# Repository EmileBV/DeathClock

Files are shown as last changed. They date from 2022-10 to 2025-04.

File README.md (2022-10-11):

# DeathClock
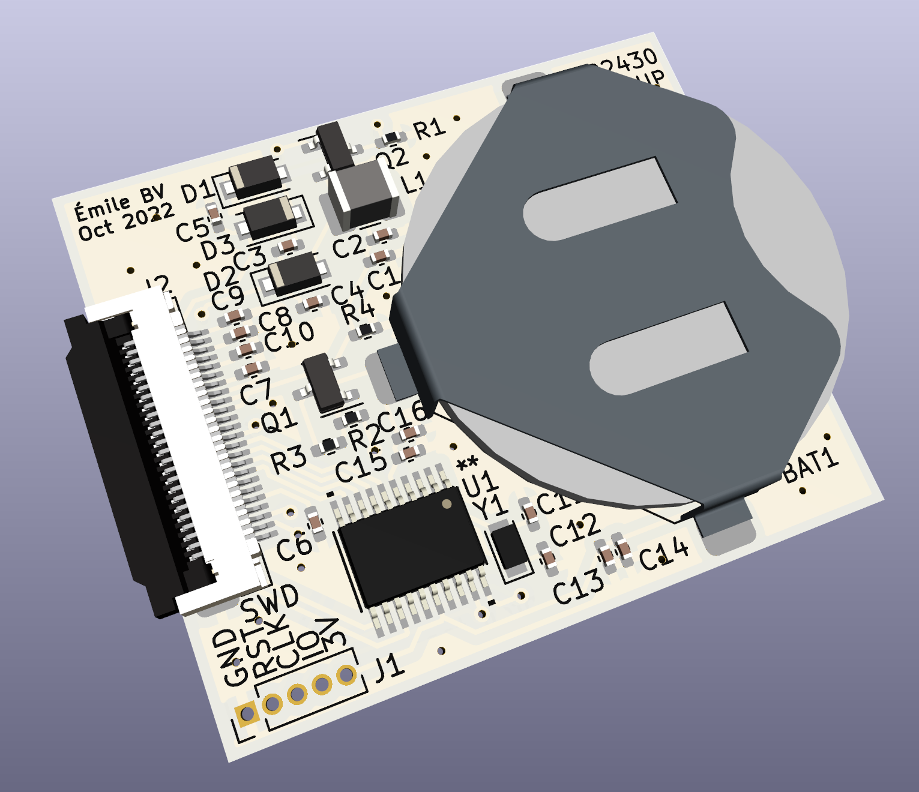
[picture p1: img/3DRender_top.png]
PCB 3D render


This project's goal to make a pocket "watch" that will last and run as long as possible and count down to a set date/time. Using an E-Paper display that will be updated maybe twice per day and a STM32L010xx MCU running on its internal low power clock to achieve very long runtime on a CR2430 coin cell.

This project is still in its very early stages right now, don't expect too much.

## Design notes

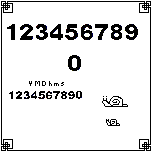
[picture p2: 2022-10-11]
img/border-1.png

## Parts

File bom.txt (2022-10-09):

screen
	https://www.mouser.ca/ProductDetail/Pervasive-Displays/E2154CS0C1?qs=81r%252BiQLm7BRJs1q0y8kw4A%3D%3D
	https://www.digikey.ca/short/02f04dr4
	E2154CS0C1 
	
mcu
	https://www.digikey.ca/short/brm0pvjz
	STM32L010C6T6
	
battery
	CR2430
	
battery holder
	https://www.digikey.ca/short/hr0fm4jj
	BH-109B-5
	
connector
	https://www.digikey.ca/short/h8t5zh5f
	FFC2B35-24-T
	
possible github library for epaper display
	https://github.com/waveshare/e-Paper

crystal
	https://www.digikey.ca/short/vbm5q2j8
	CM8V-T1A-32.768KHZ-6PF-20PPM-TA-QC

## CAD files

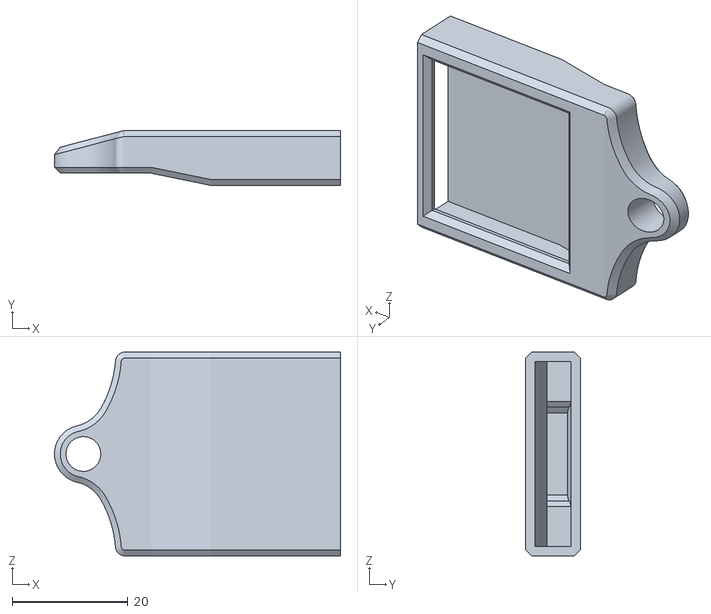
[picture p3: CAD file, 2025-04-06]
3D/printed/Case.stl
49.4 x 9.45 x 35.2

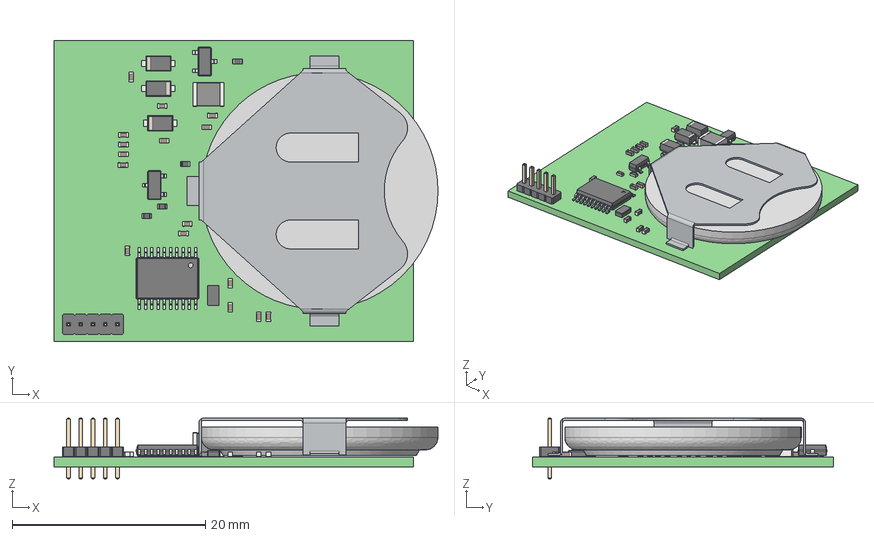
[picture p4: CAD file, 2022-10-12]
3D/step/PCB_step/DeathClock.step
39.7 x 31.2 x 6.30 mm
DeathClock PCB

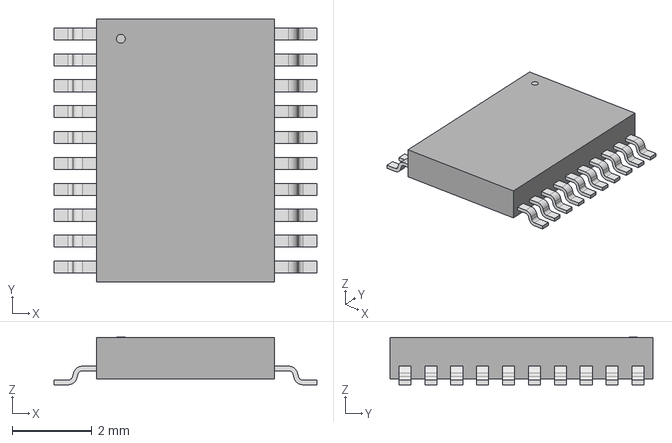
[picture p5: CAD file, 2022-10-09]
3D/step/TSSOP20.step
6.60 x 6.60 x 1.20 mm

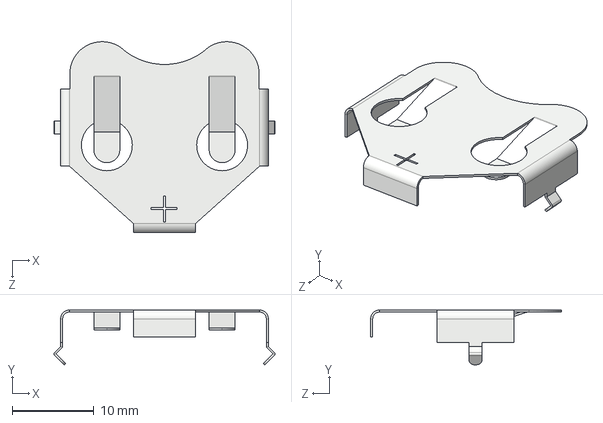
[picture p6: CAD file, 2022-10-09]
3D/step/keystone-PN3007.STEP
27.0 x 6.71 x 23.3 mm

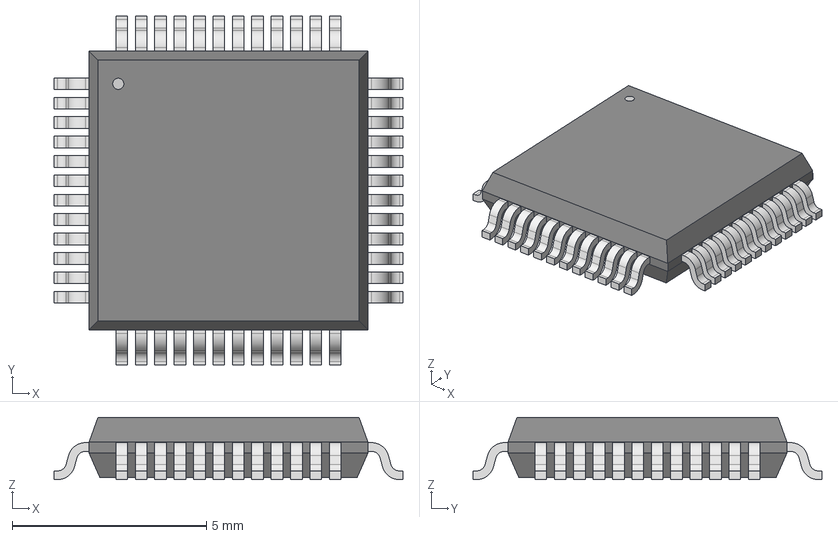
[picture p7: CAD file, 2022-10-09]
3D/step/LQFP48-7x7mm.step
8.99 x 8.99 x 1.60 mm

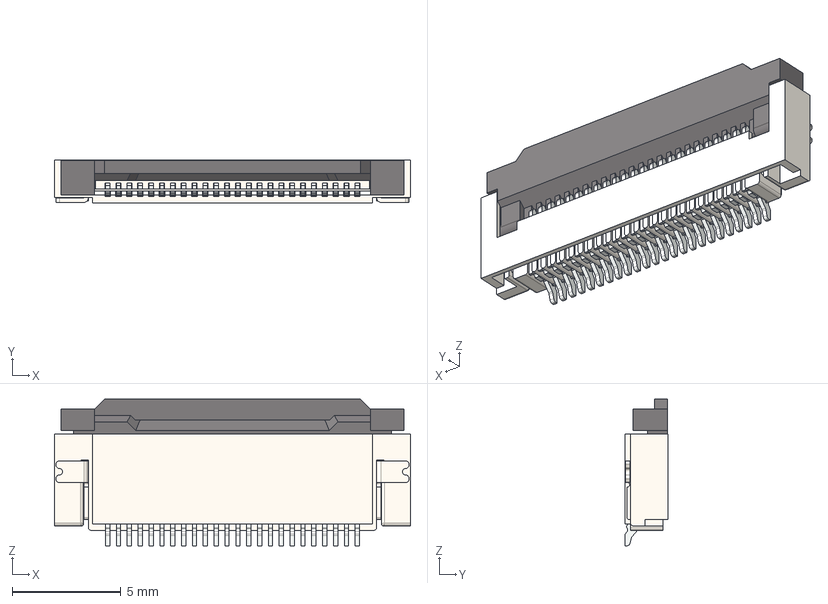
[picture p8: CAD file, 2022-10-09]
3D/step/FFC2B35-24-T.stp
16.4 x 2.00 x 6.76 mm
FFC2B35-24-T_c
FFC2B35-04-T_sp
FFC2B35-04-T_sp2
FFC2B35-24-T_p x 24
FFC2B35-24-T_h

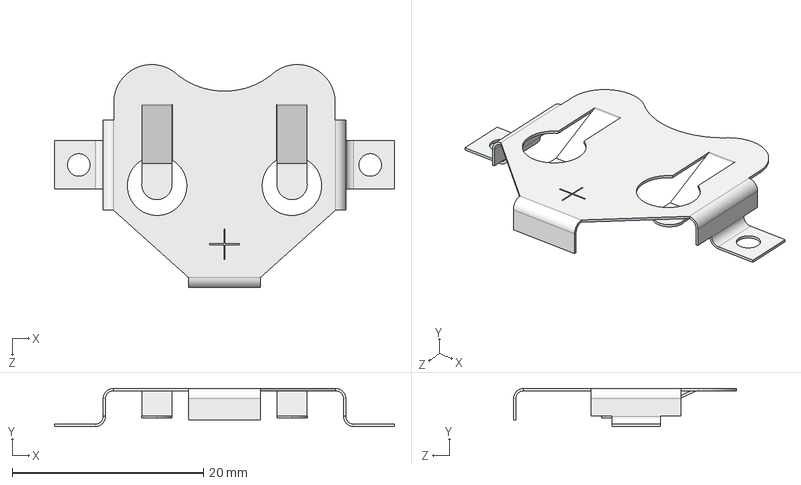
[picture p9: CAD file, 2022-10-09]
3D/step/keystone-PN3006.STEP
35.6 x 3.99 x 23.3 mm

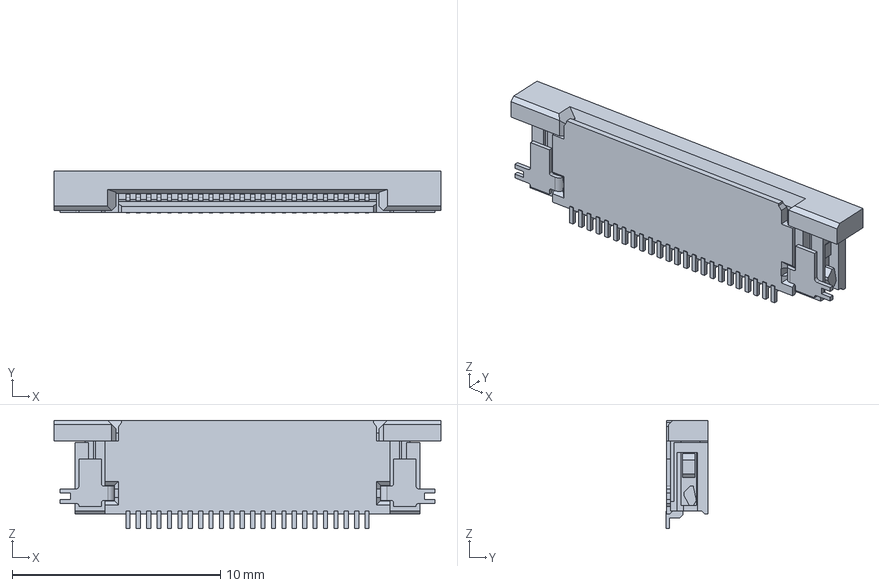
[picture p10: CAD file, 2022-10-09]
3D/step/524372471.stp
18.6 x 2.04 x 5.20 mm

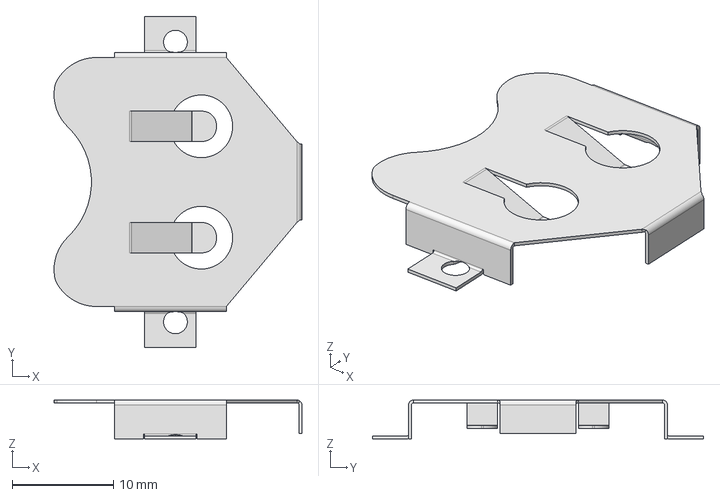
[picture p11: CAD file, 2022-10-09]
3D/step/79573131 (rev1).stp
24.5 x 32.7 x 3.85 mm

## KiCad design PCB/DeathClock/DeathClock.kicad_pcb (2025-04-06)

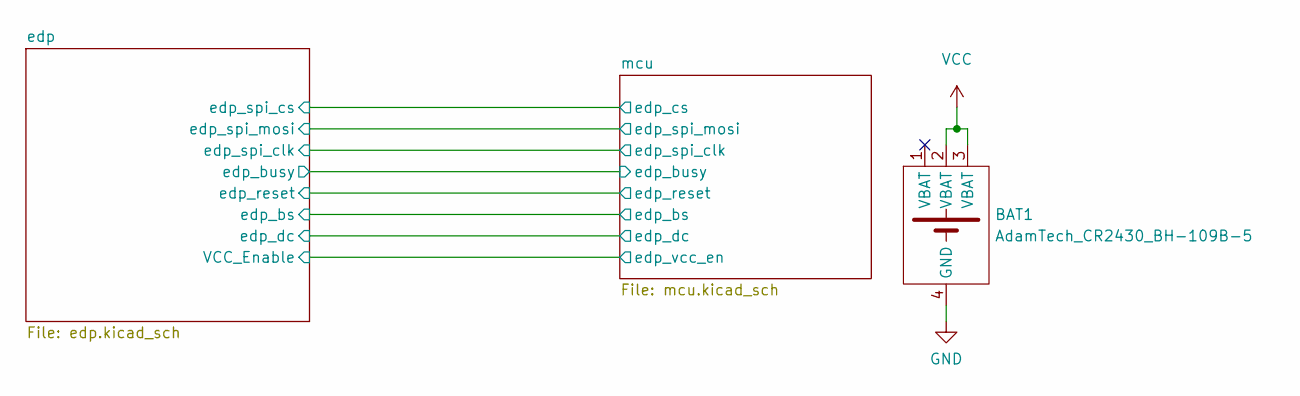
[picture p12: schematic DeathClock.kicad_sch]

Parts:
BAT1: AdamTech_CR2430_BH-109B-5; AdamTech_CR2430_BH-109B-5_num_pads

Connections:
GND: BAT1.4 (GND); also elsewhere on the board
VCC: BAT1.2 (VBAT), BAT1.3 (VBAT); also elsewhere on the board

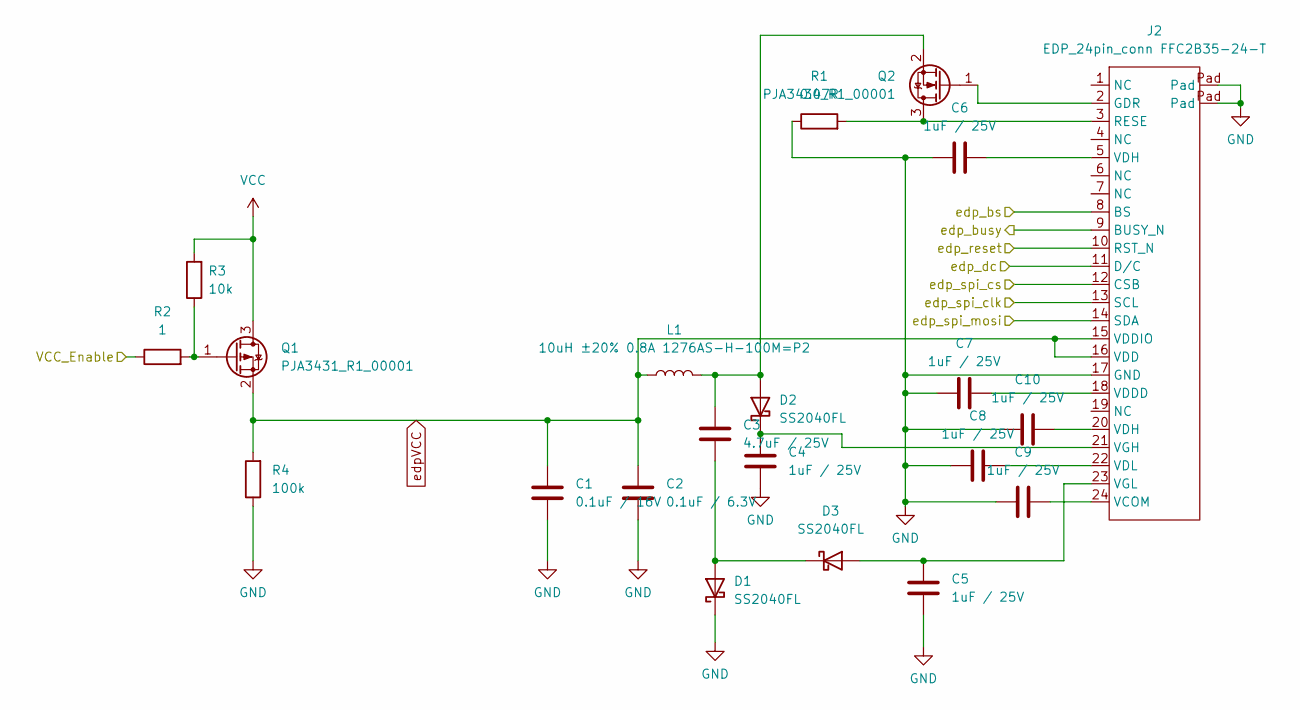
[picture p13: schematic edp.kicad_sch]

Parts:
C1: 0.1uF / 16V; C_0402_1005Metric_Pad0.74x0.62mm_HandSolder
C2: 0.1uF / 6.3V; C_0402_1005Metric_Pad0.74x0.62mm_HandSolder
C3: 4.7uF / 25V; C_0402_1005Metric_Pad0.74x0.62mm_HandSolder
C4, C5, C6, C7, C8, C9, C10: 1uF / 25V; C_0402_1005Metric_Pad0.74x0.62mm_HandSolder
D1, D2, D3: SS2040FL; D_SOD-123F
J2: EDP_24pin_conn FFC2B35-24-T; FFC2B35-24-T
L1: 10uH ±20% 0.8A 1276AS-H-100M=P2; L_1210_3225Metric_Pad1.42x2.65mm_HandSolder
Q1: PJA3431_R1_00001; SOT-23
Q2: PJA3430_R1_00001; SOT-23
R1: 0.47R; R_0402_1005Metric_Pad0.72x0.64mm_HandSolder
R2: 1; R_0402_1005Metric_Pad0.72x0.64mm_HandSolder
R3: 10k; R_0402_1005Metric_Pad0.72x0.64mm_HandSolder
R4: 100k; R_0402_1005Metric_Pad0.72x0.64mm_HandSolder

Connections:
/edp/VCC_Enable: R2.1; also elsewhere on the board
/edp/edp_bs: J2.8 (BS); also elsewhere on the board
/edp/edp_busy: J2.9 (BUSY_N); also elsewhere on the board
/edp/edp_dc: J2.11 (D/C); also elsewhere on the board
/edp/edp_reset: J2.10 (RST_N); also elsewhere on the board
/edp/edp_spi_clk: J2.13 (SCL); also elsewhere on the board
/edp/edp_spi_cs: J2.12 (CSB); also elsewhere on the board
/edp/edp_spi_mosi: J2.14 (SDA); also elsewhere on the board
GND: C1.2, C2.2, C4.1, C5.1, C6.1, C7.2, C8.2, C9.2, C10.2, D1.1 (K), J2.17 (GND), J2.Pad, R1.1, R4.1; also elsewhere on the board
unnamed: C3.1, D1.2 (A), D3.1 (K)
unnamed: C3.2, D2.2 (A), L1.2, Q2.2 (S)
unnamed: C4.2, D2.1 (K), J2.21 (VGH)
unnamed: C5.2, D3.2 (A), J2.23 (VGL)
unnamed: C6.2, J2.5 (VDH)
unnamed: C7.1, J2.18 (VDDD)
unnamed: C8.1, J2.22 (VDL)
unnamed: C9.1, J2.24 (VCOM)
unnamed: C10.1, J2.20 (VDH)
unnamed: J2.2 (GDR), Q2.1 (G)
unnamed: J2.3 (RESE), Q2.3 (D), R1.2
unnamed: Q1.1 (G), R2.2, R3.1
VCC: Q1.3 (D), R3.2; also elsewhere on the board
edpVCC: C1.1, C2.1, J2.15 (VDDIO), J2.16 (VDD), L1.1, Q1.2 (S), R4.2

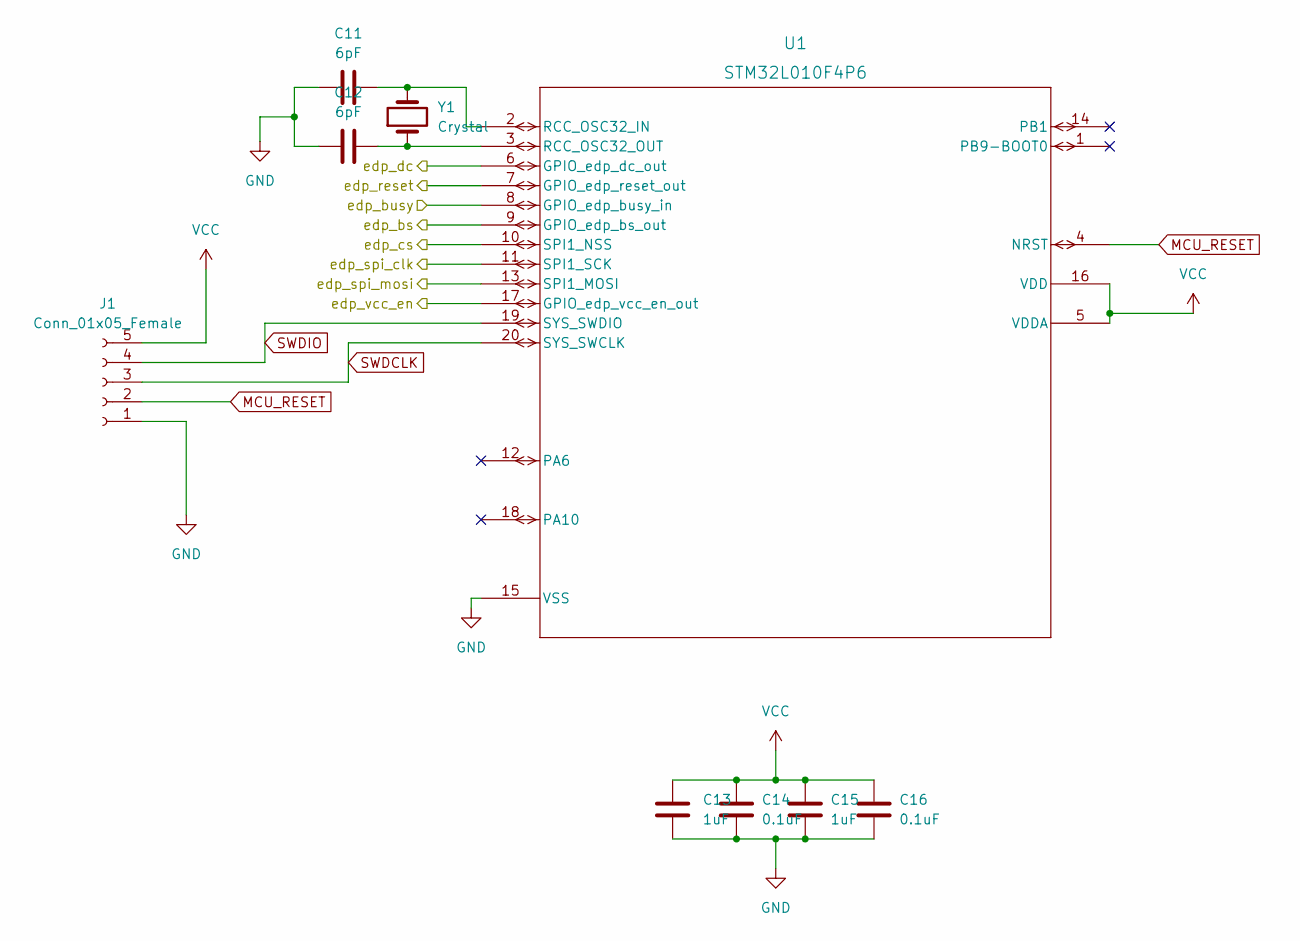
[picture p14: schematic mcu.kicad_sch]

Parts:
C11, C12: 6pF; C_0402_1005Metric_Pad0.74x0.62mm_HandSolder
C13, C15: 1uF; C_0402_1005Metric_Pad0.74x0.62mm_HandSolder
C14, C16: 0.1uF; C_0402_1005Metric_Pad0.74x0.62mm_HandSolder
J1: Conn_01x05_Female; PinHeader_1x05_P1.27mm_Vertical
U1: STM32L010F4P6; TSSOP20
Y1: Crystal; Crystal_SMD_2012-2Pin_2.0x1.2mm_HandSoldering

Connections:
/edp/VCC_Enable: U1.17 (GPIO_edp_vcc_en_out); also elsewhere on the board
/edp/edp_bs: U1.9 (GPIO_edp_bs_out); also elsewhere on the board
/edp/edp_busy: U1.8 (GPIO_edp_busy_in); also elsewhere on the board
/edp/edp_dc: U1.6 (GPIO_edp_dc_out); also elsewhere on the board
/edp/edp_reset: U1.7 (GPIO_edp_reset_out); also elsewhere on the board
/edp/edp_spi_clk: U1.11 (SPI1_SCK); also elsewhere on the board
/edp/edp_spi_cs: U1.10 (SPI1_NSS); also elsewhere on the board
/edp/edp_spi_mosi: U1.13 (SPI1_MOSI); also elsewhere on the board
GND: C11.1, C12.1, C13.1, C14.1, C15.1, C16.1, J1.1, U1.15 (VSS); also elsewhere on the board
MCU_RESET: J1.2, U1.4 (NRST)
unnamed: C11.2, U1.2 (RCC_OSC32_IN), Y1.2
unnamed: C12.2, U1.3 (RCC_OSC32_OUT), Y1.1
SWDCLK: J1.3, U1.20 (SYS_SWCLK)
SWDIO: J1.4, U1.19 (SYS_SWDIO)
VCC: C13.2, C14.2, C15.2, C16.2, J1.5, U1.5 (VDDA), U1.16 (VDD); also elsewhere on the board

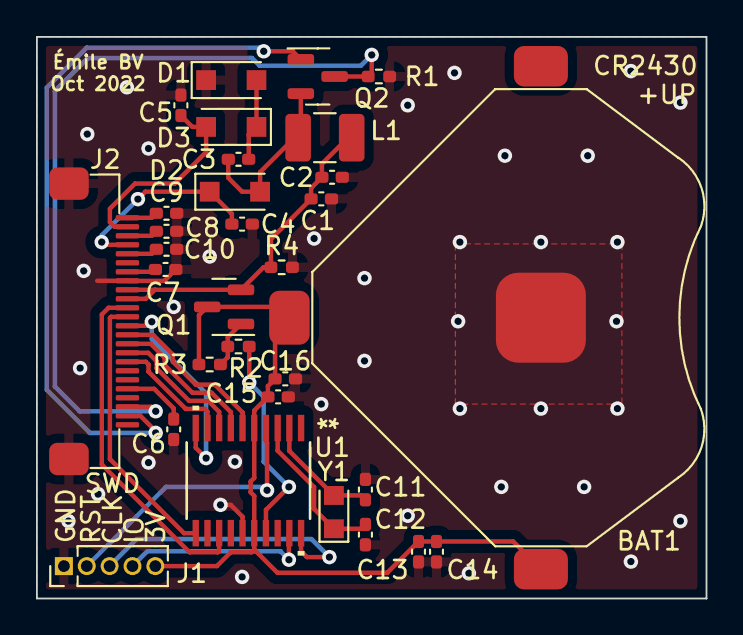
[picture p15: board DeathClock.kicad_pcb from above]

Board: 2 copper layers, 37.2 x 31.2 mm, 31 parts (0 on the bottom side), 28 nets.

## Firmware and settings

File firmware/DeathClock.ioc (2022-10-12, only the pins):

Mcu.UserName=STM32L010F4Px
PA0-CK_IN.GPIO_Label=GPIO_edp_dc_out
PA0-CK_IN.Signal=GPIO_Output
PA1.GPIO_Label=GPIO_edp_reset_out
PA1.Signal=GPIO_Output
PA13.Signal=SYS_SWDIO
PA14.Signal=SYS_SWCLK
PA2.GPIO_Label=GPIO_edp_busy_in
PA2.Signal=GPIO_Input
PA3.GPIO_Label=GPIO_edp_bs_out
PA3.Signal=GPIO_Output
PA4.Signal=SPI1_NSS
PA5.Signal=SPI1_SCK
PA7.Signal=SPI1_MOSI
PA9.GPIO_Label=GPIO_edp_vcc_en_out
PA9.Signal=GPIO_Output
PC14-OSC32_IN.Signal=RCC_OSC32_IN
PC15-OSC32_OUT.Signal=RCC_OSC32_OUT

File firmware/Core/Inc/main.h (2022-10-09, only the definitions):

#define GPIO_edp_dc_out_Pin GPIO_PIN_0
#define GPIO_edp_dc_out_GPIO_Port GPIOA
#define GPIO_edp_reset_out_Pin GPIO_PIN_1
#define GPIO_edp_reset_out_GPIO_Port GPIOA
#define GPIO_edp_busy_in_Pin GPIO_PIN_2
#define GPIO_edp_busy_in_GPIO_Port GPIOA
#define GPIO_edp_bs_out_Pin GPIO_PIN_3
#define GPIO_edp_bs_out_GPIO_Port GPIOA
#define GPIO_edp_vcc_en_out_Pin GPIO_PIN_9
#define GPIO_edp_vcc_en_out_GPIO_Port GPIOA

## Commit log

2022-10-09 added second mosfet to toggle epd power
    [DeathClock.kicad_pcb]
2022-10-09 made the coin cell symbol 4 pins to make drc happy
    [DeathClock.kicad_pcb, DeathClock.kicad_sch, edp.kicad_sch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]
2022-10-10 moved some labels around and added SWD header pin names
    [DeathClock.kicad_pcb]
2022-10-10 added silkscreen stuff for user-friendliness
    [DeathClock.kicad_pcb]
2022-10-11 moved text around a bit and added snail
    [DeathClock.kicad_pcb]
2022-10-11 added image of 3D render of PCB
2022-10-12 rework PCB to export step file properly and start of case cad
    [DeathClock-B_Cu.gbr, DeathClock-B_Mask.gbr, DeathClock-B_Paste.gbr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]
2022-10-12 case body mostly completed
    [DeathClock.cfg]
2025-04-06 updated to kicad 9.0
    [Case.stl, DeathClock.cfg, DeathClock.kicad_pcb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]

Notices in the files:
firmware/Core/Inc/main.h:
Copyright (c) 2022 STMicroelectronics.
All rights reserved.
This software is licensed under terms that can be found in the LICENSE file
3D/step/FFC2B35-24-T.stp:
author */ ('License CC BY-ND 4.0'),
